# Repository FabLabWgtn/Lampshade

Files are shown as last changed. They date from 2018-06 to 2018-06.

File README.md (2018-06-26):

# README

Wendy Neale, Designer and Director of [Fab Lab Wgtn](https://www.fablabwgtn.co.nz/), in New Zealand was the Mentor-in-Residence at [Fab Lab UAE](http://fablabuae.ae/) from January to July 2018, during Fab Academy. In the fifth week of Fab Academy, the Lab hosted the first Mini MakerFaire in the UAE. Fab Lab UAE asked her to design a paper lampshade for some casual workshops that would run during the four-day event. Here is what she did:

With everything else going on in the Lab, I found myself with only a couple of days to prepare, so I spent some time cutting and folding paper and trying out some ideas. I needed to work more quickly, so I decided to build on some existing work rather than developing it from the beginning. Looking at the Crease Patterns created by RJ Lang, I decided to adapt the CamphorPot8, opus 679. Referencing this pattern added to the story as I was able to talk about the work he did on the [Deployable Solar Array](https://compliantmechanisms.byu.edu/node/892), where he built on someone else's work, showing the benefit of not starting from zero. It's also a great example of the broader uses of paper-folding!

RJ Lang's website is full of great patterns that he has developed, and if you look around it, you will find that he has very clear copyright statements. He is open to uses of his patterns for educational purposes as long as you have his written permission and always give credit to him for his crease patterns.

I drew up a file in Illustrator and tested it and modified it a number of times. One day, I might make it in something else, but I was in a hurry and wasn't too concerned about other people being able to edit it.”

After the four-day event, she collaborated with Etienne Moreau, Technical Demonstrator at [Fab Lab Wgtn](https://www.fablabwgtn.co.nz/) in New Zealand from February to July 2018, to work on the lamp prototype she started and create a 2-hour workshop to help people learn to make their own custom lampshades! Along with the file and material settings, you’ll find the workshop run-sheet including steps to learn how to do it on your own!

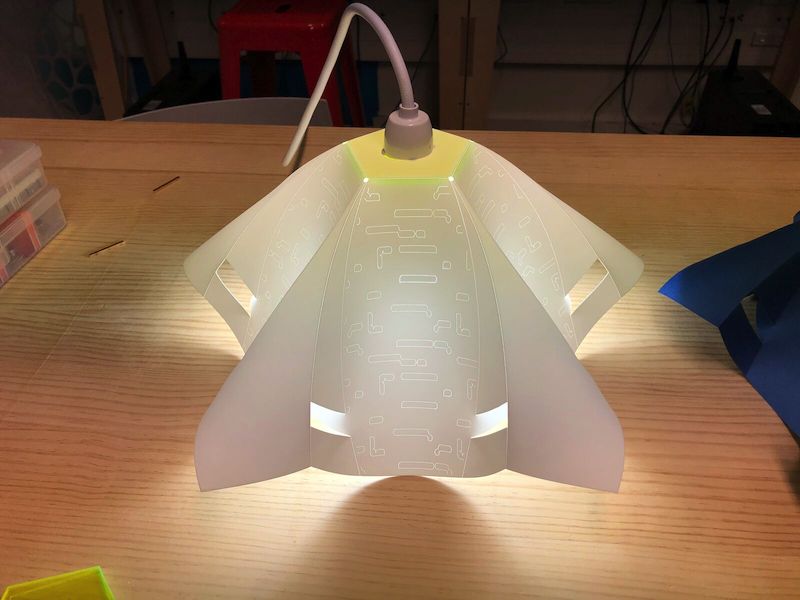
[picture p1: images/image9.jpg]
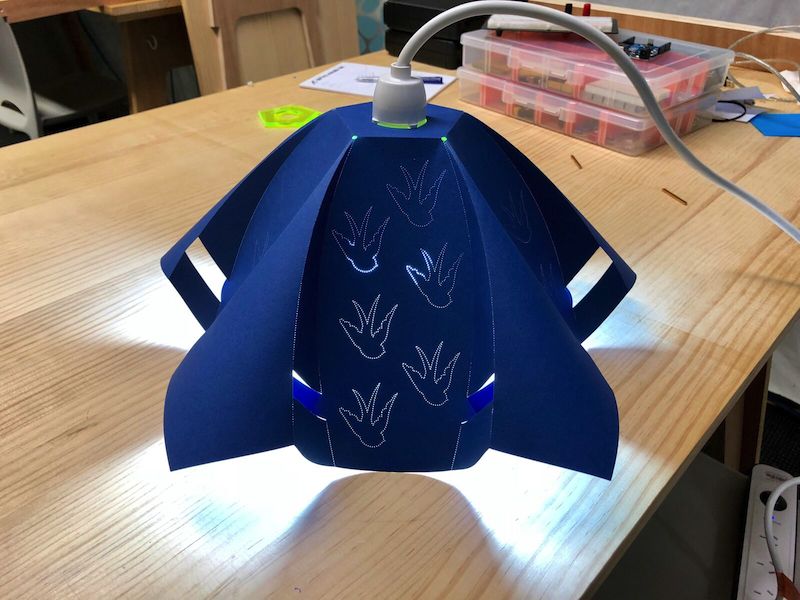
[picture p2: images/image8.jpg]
 

> *Fab Lab Wgtn Lampshade (white model) and a custom model made by a community member (blue model)*

---

## **Files in this repo**

  - a **Lampshade template** in **.ai** and **.dxf** format to make your custom design

  - the [Materials list, settings & machine specs](Materials-list-settings-machine-specs.md)

  - a [Workshop runsheet](DIY-instructions-workshop-runsheet.md) to run your own Lampshade workshop

  - the [Instructions to hand out to participants](Instructions_participants_workshop.pdf) attending the workshop

  - **Fab Lab Wgtn’s Lampshade** ready-to-cut sample in **.ai** and **.dxf** format

  - **others custom designs** we made at Fab Lab Wgtn in **.ai** and **.dxf** format

----

## **Machine & software used**

To create our lamps, we only used:

- a **laser cutter** (machine/process available in many Fab Labs - ours is a ILS12.150D Universal, powered with a 105W laser unit, with a bed-size of 1219.2x609.7mmm)

- **Adobe Illustrator vector drawing software** (a good free & open source alternative is Inkscape!)

---

## **Materials recommended**

So far, we made great lampshades out of

- **0.6mm polypropylene** (the white model) or **0.35mm colored craft paper** (the dark blue model)

- and **3mm acrylic** (for the light socket fitting)

----------

## **Layout of the Lampshade template**

The page size is equal to our laser cutter bed size. There are 6 layers in the document and 3 art-boards (the Universal Laser print driver can deal with more than one art-board). There are also graphic styles already pre-set to prepare the file for laser cutting (pure red 0.1 pt stroke to cut, pure green 0.1 pt stroke to make creasing lines)

  - **The 3 art-boards are**:

    - art-board 1 - to cut the final lamp

    - art-board 2 (below) - to work on your very own lamp design
    - art-board 3 (right) - to cut the acrylic fitting

--

  - **The 6 layers are**:

    - the notes & black guides (on art-board 1)

    - the lamp red cutouts (on art-board 1)

    - the lamp green creasing lines (on art-board 1)
    - a draft layer dedicated to prep your design (on art-board 1)

    - the acrylic fitting (on art-board 3 - on the right side)

    - the logos & credits for the acrylic fitting (on art-board 3 - on the right side)

--

  - **Black lines are guides**:

    - The thin grey dotted lines are symetry guides

    - The thick black lines are guides to align your design with the first petal of the Lampshade

--

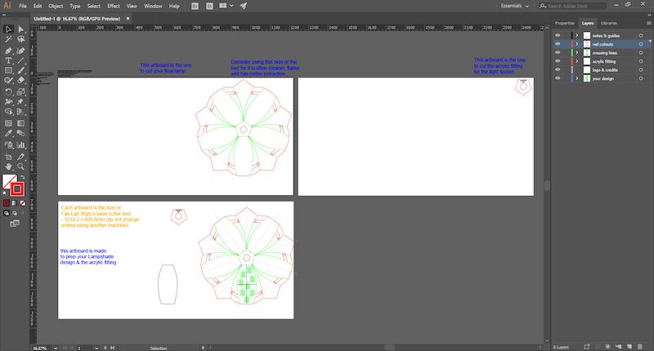
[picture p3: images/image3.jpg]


>  *what the Lampshade vector template looks like in Illustrator*

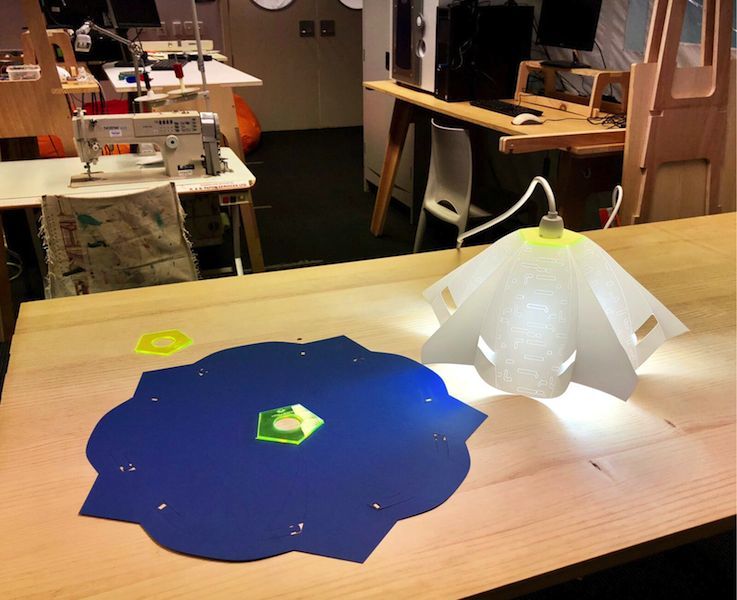
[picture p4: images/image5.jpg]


> *a ready-to-fold Lampshade & a finished model*

----------
## **Workshop layout - create a “2-hour make your own lampshade” workshop**

- **License** - Creative Commons Attribution-NonCommercial-ShareAlike 4.0 International License

  Creative Commons Attribution-NonCommercial-ShareAlike 4.0 International License.

- **original design** - Wendy Neale, based on an existing pattern by R. J. Lang

- **workshop creators** - Wendy Neale & Etienne Moreau (Fab Lab Wgtn)

- **creation date** - May 2018

- **workshop type** - hands-on workshop, 2 hours

- **advised number of participants** - 6

- **machine needed** - laser cutter with at least a 500x500mm bed

- **software needed** - vector drawing software like Inkscape or Illustrator

- **suggested materials** - for each lamp, a 500x500mm piece of 0.6mm white polypropylene or 0.35mm colored paper + a 85x80mm piece of 3mm acrylic

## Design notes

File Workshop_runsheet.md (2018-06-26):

# Workshop runsheet - make your own Lampshade in 2 hours



### **WORKSHOP LAYOUT**

  - **original design** - Wendy Neale, based on an existing pattern by R. J. Lang
  - **workshop creators** - Wendy Neale & Etienne Moreau (Fab Lab Wgtn)
  - **date** - May 2018
  - **license** - Creative Commons Attribution-NonCommercial-ShareAlike 4.0 International License
  - **workshop type** - hands-on workshop, 2 hours
  - **advised number of participants** - 6
  - **machine needed** - laser cutter with at least a 500 x 500mm bed
  - **software needed** - vector drawing software like Inkscape or Illustrator
  - **material to be cut** - for each lamp, a 500 x 500mm piece of 0.6mm white polypropylene or 0.35mm colored paper + a 85 x 80mm piece of 3mm acrylic
----------
**ABOUT THE LAMPSHADE**

  Inspired from Robert J. Lang’s [CamphorPot8, opus 679](http://www.langorigami.com/crease-pattern/camphorpot8-opus-679) origami pattern, this Lampshade was created in Dubaï by Wendy Neale, while working at [Fab Lab UAE](http://fablabuae.ae/). It was then adapted in Wellington by Etienne Moreau ([Fab Lab Wgtn](https://www.fablabwgtn.co.nz/)) to help anyone custom their own Lampshades & run workshops!

  The lamp’s story is a great illustration of what we can make & achieve in an open design world with shared digital fabrication spaces all around the world available to anyone!

----------
**TODAY'S PLAN**

  In 2 hours, we’ll make a plan to make our lamps, find cool illustrations on the web, prepare your unique design with Adobe Illustrator software, cut your lamp with the laser cutter together, fold it into its final shape & wire it. By then, your creation will be ready to be put anywhere back home or at your office!

  - 0️⃣  welcome everyone & workshop start - **5-10 min**
  - 1️⃣  making & lighting for well-being - **5 min**
  - 2️⃣  find & download free illustrations - **10** **min**
  - 3️⃣  create a custom lampshade - **40 min**
  - 4️⃣  engrave the design - **5-8 min** cut time max per person
  - 5️⃣  crease the lamp - **15 min**
  - 6️⃣  wire the lamp & light it up - **10 min**

---

###  **WHAT WE’RE GOING TO USE TODAY**

- **Adobe Illustrator** (or alternatively any vector drawing software like Inkscape)

Vector drawing softwares are a great tools to draw stuffs in 2D, from illustrations to designing lampshade, paper boxes or other cools projects! It’s also a great tool to create something we want to laser cut!

And the good thing is, it’s pretty to learn and get started. We’ll use it to adapt an illustration created by someone else and use it as a base for your lampshade design.

- **A laser cutter**

The laser cutter is the single most used machine in Fab Labs over the world. A laser beam is created and focused to a single point to help us cut/engrave wood, plastic, paper, fabrics and other fun materials & make the thing we designed for us.

Pairing vector drawing & laser cutting is a powerful thing, and one of the best ways to start experiencing digital fabrication!

----------
### **BEFORE MAKING A LAMPSHADE ON YOUR OWN ⚠️**

  - **We recommend buying everything prior to starting these instructions** (for example, you need to know the width of your light socket to set the right dimensions for the acrylic fitting)

  - The workshop & these instructions aren't **meant to be a full introduction to Illustrator & laser cutting**! If you don’t know how to use them, [find a local Fab Lab](https://www.fablabs.io/labs) to learn & practice on simple projects first :)

  - if you don’t have one already, **download a vector drawing software like Adobe Illustrator (not free) or Inkscape (free) and learn the basics through tutorials!**

----

### **BEFORE RUNNING THE WORKSHOP YOURSELF ⚠️**

  - get all the materials you need
  - buy matching lights bulbs, sockets & power leads
  - test out the settings for the chosen material on your own machine
  - make a test lamp with your own design to test the whole workflow

  - pre-cut all lamps but one to save time - cut the last one during the workshop to show participants
  - if you pre-cut the lamps, don't forget to use the workshop Illustrator template and to keep the "outside paper pattern" to be able to engrave the design on the exact same spot

  - adapt the acrylic fitting dimensions to the light sockets you bought
  - pre-cut all acrylic fittings but one to save time - cut the last one during the workshop to show
  - if you pre-cut the acrylic fittings, don't forget to use the workshop Illustrator template and to keep the "outside acrylic pattern" to be able to engrave the participants' names on the exact same spot

  - turn on the machine, focus on the material & choose the right settings
  - print these instructions for everyone

----------

## 0️⃣  **WELCOME EVERYONE & START WORKSHOP - 5-10 min**

  - welcome everyone to the space you run the workshop in
  - explain briefly the goals of the workshop & what can everyone expect
  - introduce yourself, talk about your experience and how this workshop is exciting to you
  - ask everyone to introduce themselves: where they’re from, their background, experience with digital fabrication (both machine & software side) and what they’re trying to achieve participating in this workshop
  - thank everyone & explain the outline of the workshop

----------

## 1️⃣  **MAKING & LIGHTNING FOR WELL-BEING - 5 min**

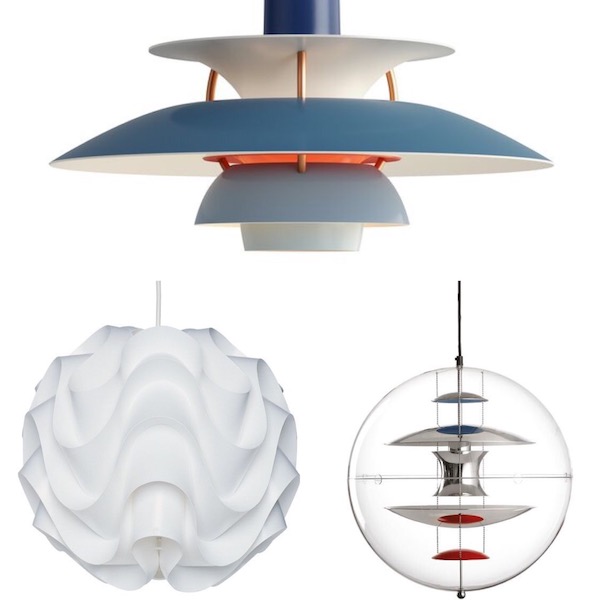
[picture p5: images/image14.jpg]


*read for more context about lighting at home & for well-being, these pictures are taken from* [*The Little Book of Hygge: Danish Secrets to Happy Living*](https://www.theguardian.com/books/2016/sep/29/book-of-hygge-louisa-thomsen-brits-review) *written by Meik Wiking*

----------
- **why make a lamp ourselves instead of buying one?**
  - it’s always an invaluable learning opportunity to make something yourself 🙂
  - using a laser cutter, you’ll get spend a great moment in a local community space
  - you’ll learn to create something, not existing on the market and fitting your needs & personality
  - making locally rather than buying something made abroad & shipped is better for the planet
  - you’ll start taking control back over the objects & physical world around you (invent, repair, adapt, make things again)

- **key take-aways about lighting for well-being**
  - the lower the temperature of the light, the best for our eyes & bodies
  - between 3,000K (incandescent lamp) & 1,800K (sunset, candle flame, wood fire) is ideal
  - as much, try to eliminate visual glare, obscure the light source to only emit reflected light
  - instead of having one bright spot in the room, have several warm light spots
  - the position of lighting is the most important thing in your home, more than room layout
  - making & Fab Labs are an opportunity to create lightnings for you & your well-being

----------

## 2️⃣  **FIND & DOWNLOAD FREE ILLUSTRATIONS - 10 min**

Because designing an illustration from scratch is a whole other business, people created amazing websites where you & I can download illustrations made by real designers for free. Pretty cool uh? We’ll download one you like to start!

-  go to The Noun Project

- choose a simple illustration of something waves or animals (see the example below to know how to choose)

💡 *Our goal here is to have as few lines as possible. The more lines, the longer the cut. Choose your design wisely!*

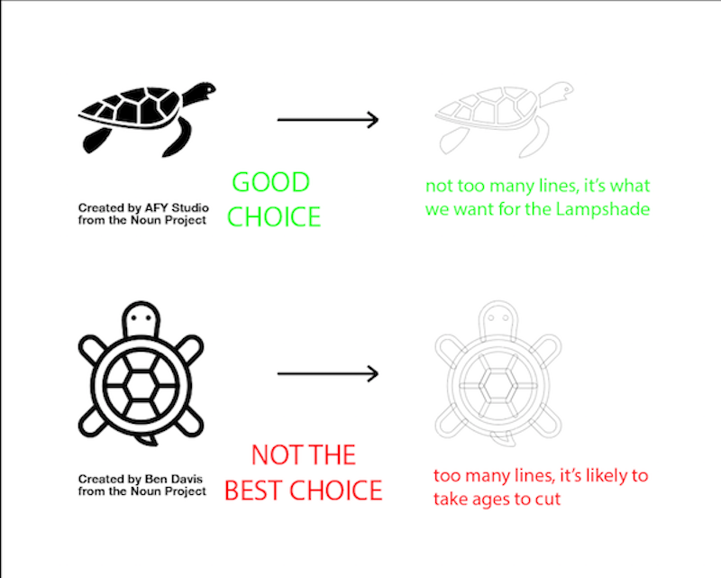
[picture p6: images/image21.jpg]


⚠️  *Before hitting “Download”, look at the license protecting the design (hover the small icons next to the download button with your mouse) & wonder if the use you’ll make of it matches the license*

- choose the SVG option

- create an account or log in

- choose the Creative Commons option

- open it with Adobe Illustrator

⚠️  *Don’t delete the credits, they’re important - note them / take picture for later reference. Deleting them and using the design in one of your project just like that = plagiarism!*

**→ good job choosing your illustration, let’s open it in Illustrator to adapt it to create your own Lampshade**

----------

## 3️⃣  **CREATE A CUSTOM LAMPSHADE - 40 min**

💡 *We use Adobe Illustrator at Fab Lab Wgtn - hence, the following instructions are named after the Illustrator ones, but you’ll easily find how to do it in another software on Google!*

**STEP 3.1 - ADAPT THE ILLUSTRATION TO CREATE YOUR DESIGN**

The person who created the illustration we just downloaded has surely done a bunch of stuffs to it: grouping elements, organizing the elements in layers & masks, using clipping masks to create the shapes, and more Illustrator complicated stuffs!

So the first step will be to get rid of all of this to only a simple illustration ready to be modified!

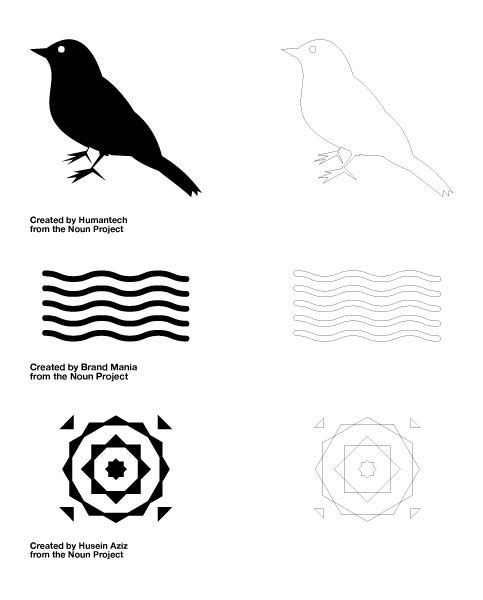
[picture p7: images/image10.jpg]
 *examples of illustrations downloaded from The Noun Project and “cleaned” to create our Lampshade design*

Now in Illustrator, make sure you:

 - **get rid of all the groups**
= select everything with “ctrl + A”, then do “ctrl + shift + G” several times to ungroup everything

 - **get rid of all the compound paths**
= select everything with “ctrl + A”, then go to the top menu to “object” > “compound path” > “release”

 - **get rid of all the clipping mask**
= select everything with “ctrl + A”, right-click on one of the design lines, then select “cancel clipping mask” if there’s any

 - **get rid of all the double/superposed lines**
 = erasing one line to see if there’s any doubloons hiding underneath it, then do “ctrl + Z” to cancel the deletion

 - **save your work with “ctrl + s”**

**→ good job preparing your illustration, let’s now create our “illustration pattern” over the whole Lampshade**

----------

**STEP 3.2 - OPEN THE LAMPSHADE TEMPLATE WE PREPARED**

To make this 2-hour workshop available to anyone & focus on the essential, we create a ready-to-use Lampshade template in Illustrator! We organised it and prepared everything you’ll need to make your own Lampshade. Before opening it, here is what it looks like and what’s inside!

 *what the Lampshade template looks like in Illustrator*

💡 *Each art-board size is the same as Fab Lab Wgtn laser bed size (1219x609mm)*

- open the Lampshade template

- **The 3 art-boards are**:

  -  art-board 1 - to cut the final lamp
  - art-board 2 (below) - to work on your very own lamp design
  - art-board 3 (right) - to cut the acrylic fitting

- **The 6 layers are**:

  - the notes & black guides (on art-board 1)
  - the lamp red cutouts (on art-board 1)
  - the lamp green creasing lines (on art-board 1)
  - a draft layer dedicated to prep your design
  - the acrylic fitting (on art-board 3 - on the right side)
  - the logos & credits for the acrylic fitting (on art-board 3 - on the right side)

- The **thin grey dotted lines** are symmetry guides

- The **thick black lines** are guides to align your design with the first petal of the Lampshade

----------

**STEP 3.3 - FROM ONE ILLUSTRATION TO A PETAL-SIZED PATTERN**

Now that your illustration is ready, we can create a pattern of illustrations on the first petal of the Lampshade (out of 5): we’ll adapt the scale, the orientation, the alignment and the number of illustrations we want before replicating this petal over the whole Lampshade!

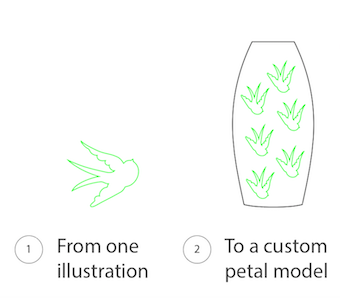
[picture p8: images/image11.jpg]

*adapting & replicating our illustration to create a petal-sized design*

💡 *again, the smaller the result & the more illustrations, the longer the cut! We’d recommend making your first lamp with a design not too small & not too complex!*

Now in Illustrator, make sure you:

- in your illustration file, select only the design and copy it with “ctrl + C”
- now in the Lampshade template, zoom on the black petals
- paste your illustration with “ctrl + V”

- **change your illustration style** - go to “window” in the top menu > click on “graphic styles” > select the green outline one - this graphic style will set the fill color to clear, the outline color to pure green and the stroke weight to 0.1 pt
- group all your illustration lines together (use ctrl + G) - now, wherever you click, it will select everything by default
- move your illustration over one of the locked black petals

- **change the scale of your illustration** (in the top menu, go “window” > “properties” > tick the “keep the ratio” box and update the width or height to a small-enough size)
- **change the orientation of your illustration** (hit “R” key, click & drag to turn) - the top of petals are the one adjacent to the pentagon in the middle of the Lampshade
- **create an “illustration wallpaper" on the petal by multiplying your illustration** (copy with “ctrl + C”, paste with “ctrl + V” & place by selecting and moving it)
- **align or distribute all your illustrations in a nice way** (in the top menu, go “window” > “align” and check out the different options)

- select everything inside the petal and group it together with “ctrl + G”

- **save your work with “ctrl + s”**

**→ good job, your petal-sized design is finished**

----------

**STEP 3.4 - FROM A PETAL-SIZED PATTERN TO A WHOLE LAMPSHADE**

Now that out petal-sized pattern is ready, we will just copy it, place it over the next petal and repeat these steps to finish our Lampshade design. And Illustrator has handy functions that will help us do it in just a few steps!

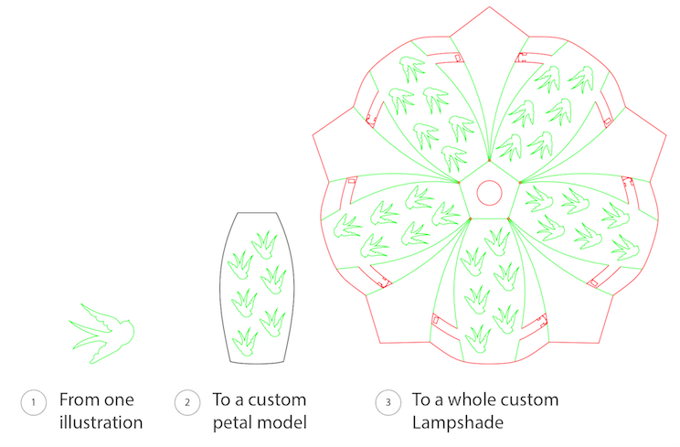
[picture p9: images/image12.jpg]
 *all 3 steps from one illustration to a whole custom Lampshade*

Now in Illustrator, make sure you:

- hide the layer with the black guides - go to the “layer menu” and click on the small eye next to the “notes & guides” layer - all the black guides and notes should disappear

- select your illustrations group from the petal model
holding the shift key, select the red circle
releasing the shift key, click on the red circle again (should appear thicker)
- go to the “align menu”, select the second option - horizontal align center
- your illustrations group should now be over the lamp’s first petal without touching the edges

- select your illustrations group again
- hit the “R” key to enter the rotation mode
- holding the “alt” key, click on the red circle’s center - a dark rotation menu should open
- you want to set the angle to 72° and make sure you click on “copy” (not on “OK”)
- hit “ctrl + D” to repeat the last action and place your illustrations group around the Lampshade

- select the whole Lampshade and move it to the top-left artboard

- save your work with “ctrl + s”

**→ congratulations, your custom lamp design is finished**

----------
**STEP 3.5 - CUSTOMISE YOUR ACRYLIC FITTING**

Now that our lamp’s design is finished, we just have to custom the acrylic fitting! This part is not to be forgotten, it will hold the light socket & bulb firmly in place

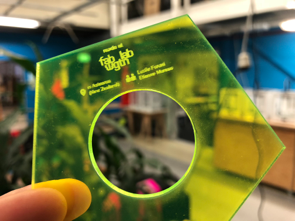
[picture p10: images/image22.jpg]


- go on the top-right artboard, double-click on the text box

- write your name, the date and the place where you created the design!

- save your work with “ctrl + s”

**→ congratulations, your lamp’s acrylic fitting is now finished too**

----------

## **4️⃣ CUT THE LAMP & THE ACRYLIC FITTING**

For this workshop to be short enough, we pre-cut some off the lamps & acrylic fittings! But we’ll cut a whole one from the start for you to understand how it works and enjoy the process. Then we’ll engrave everybody’s lamp design and acrylic fittings!

Here are a few troubleshooting tips before cutting the lamp & the acrylic fitting:

- we need to focus the laser cutter perfectly for each material
- we need to use only perfectly flat materials as much as possible
- we’ll cut all the green lines (creasing lines & your design) first, then the red lines to avoid material warping and its consequences
- to avoid having burnt traces under your material, we will spread sheets of classic print paper under your material before adding the polypropylene on top
and last, we’ll time your file to know exactly how long it will take (we recommend 10 min max for one lamp)

💡 *It is very important to actively supervise the machine during the cut! This is not the time to hang in the other room and chat with everyone. If you’re not confident enough, better ask someone to check your file and remind you all the health & safety practices* ;)

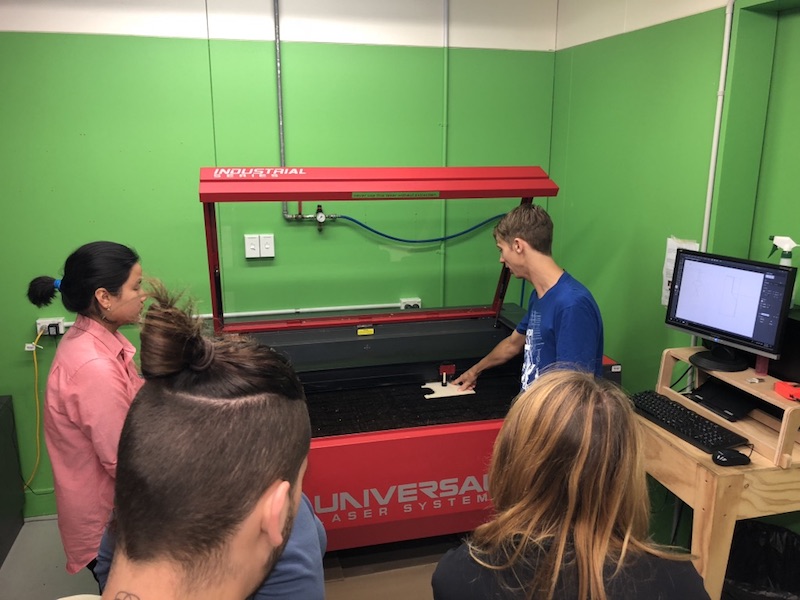
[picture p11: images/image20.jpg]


- Once the cut is done, before touching/removing your material, we will check if it’s cut all the way through:

- if not, launch a new job only with the red lines (deleting or hiding the green ones)
if yes, we can safely remove your material

**→ your custom lamp & acrylic fitting are now cut and ready to be creased**

----------

## 5️⃣  **CREASE THE LAMP - 15 min**

 *a ready-to-fold Lampshade & a finished model*

Now that our lamp is cut, we want to crease it & gently encourage it to be the shape it secretly wants to be! Don’t try to fold it straight away for it would ruin the result!

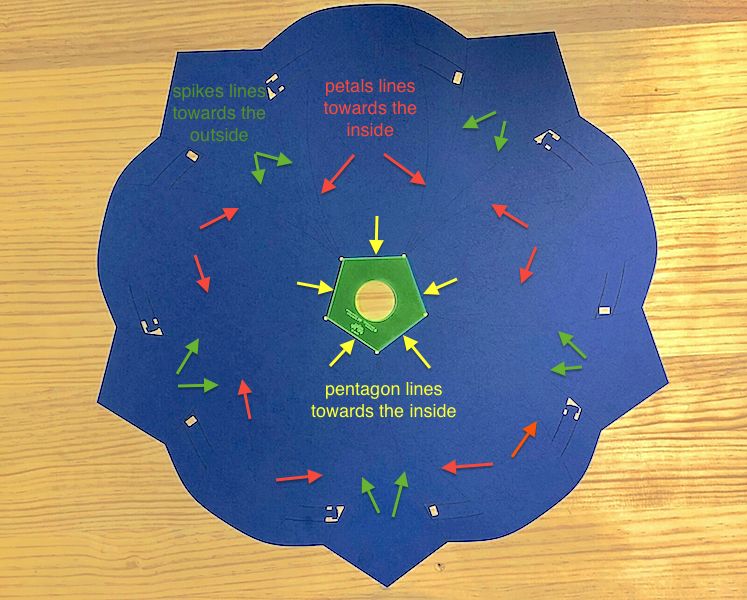
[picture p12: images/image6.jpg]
 *the creasing instructions*

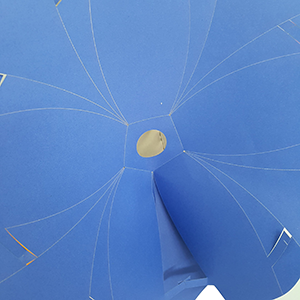
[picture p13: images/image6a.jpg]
 *the creasing instructions*
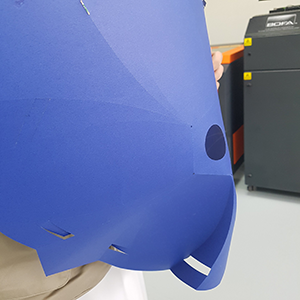
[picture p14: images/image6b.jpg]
 *the creasing instructions*

The top of your lamp will be the outside, while the bottom (with the slight burnt traces from the laser cutter) will be the inside.

- step 1 - crease the pentagon lines from the outside towards the inside
- step 2 - crease the petals edges lines from the outside towards the inside towards the inside
- step 3 - crease the “spikes” edges lines from the inside towards the inside towards the outside
- step 4 - gently squeeze each male latch inside each adjacent female latch
- step 5 - once you’ve attached all the latches together, the lamp should fold itself into its final shape

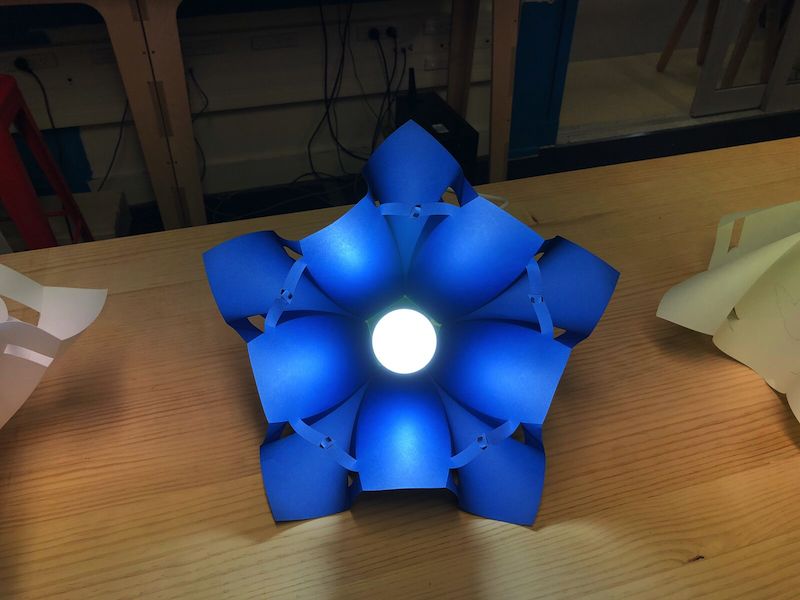
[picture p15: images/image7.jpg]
 *what the Lampshade inside looks like once creased and all latches attached*

Remember to take time check the creasing lines around the whole lamp & creasing just a little more where needed to get a nice, consistent symmetrical result!

  →  **congratulations, your custom lampshade folded in its final origami flower shape :)**

----

## 6️⃣  **WIRE THE LAMP & LIGHT IT UP - 5 min**

⛔️ ⚠️  ***Wiring up electrical appliances is a serious matter and the results of an amateur job could be devastating for your you & those around you. The Internet is not enough and bad/insufficient advices are too common. So if you’ve never done it before, I very strongly recommend you to seek help in a local Fab Lab or to someone with the right experience / expertise to walk through it.***

The steps are to:

  - screw the light socket both from the inside and the outside of the acrylic fitting for a nice & strong fit
  - wire up the power lead to the light socket
  - plug the now all wired lampshade
  - enjoy the result!

  →  **congratulations, you made your first custom lampshade :) Don’t forget to share your creations with us on** [Facebook](https://www.facebook.com/FabLabWGTN/) **or** [Instagram](https://www.instagram.com/fablabwgtn/)**!**



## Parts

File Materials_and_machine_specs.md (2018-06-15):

# Materials list, settings and machine specs

## **Machine - laser cutter specs**

To create our lamps, we only used a laser cutter (machine/process available in many Fab Labs)

- Fab Lab Wgtn's laser cutter is a ILS12.150D Universal
- powered with a 105W laser unit
- with a bed-size of 1219.2x609.7mmm

--



> *Fab Lab Wgtn’s laser cutter!*

----------
## **Material tests**

So far, we made great lampshades out of

  - **0.6mm polypropylene** (the white model) or **0.35mm colored craft paper** (the dark blue model)

  - and **3mm acrylic** (for the light socket fitting)

--

We also tested the following materials for the lamp without much success

- **0.45mm craft paper was too thick**, it made the creasing too difficult

- **0.15mm & 0.20mm craft paper was too thin**, the final structure couldn’t hold itself

--



> *Fab Lab Wgtn Lampshade, made of white polypropylene with a yellow fluo acrylic fitting*

----------
## **List of materials for one lamp**

To create one lamp and light it up, we recommend getting

- a 500x500mm piece of **0.6mm polypropylene** or **0.35mm colored craft paper**

- a 85x80mm piece of **3mm acrylic**

- a **light bulb** (between 1,800K and 3,000K)

- a **light socket** not too large (we used one with 33mm diameter & found a matching light bulb)

- a **power lead** (prior to buying, think of where you’ll put it & the length you need)

----------
## **Material settings for the laser cutter**

All vectors, print in order. The **settings on the picture are for the 0.6mm polypropylene**.

**For all materials but the acrylic, you will see that the PPI for colour blue is down to 20 pulses per inch.**

**This makes a dotted line instead of a continuous line**, allowing light to escape as well as making it easier to crease the card in the direction you want it to, and create a sweet result for your customised illustrations on the petals!

--

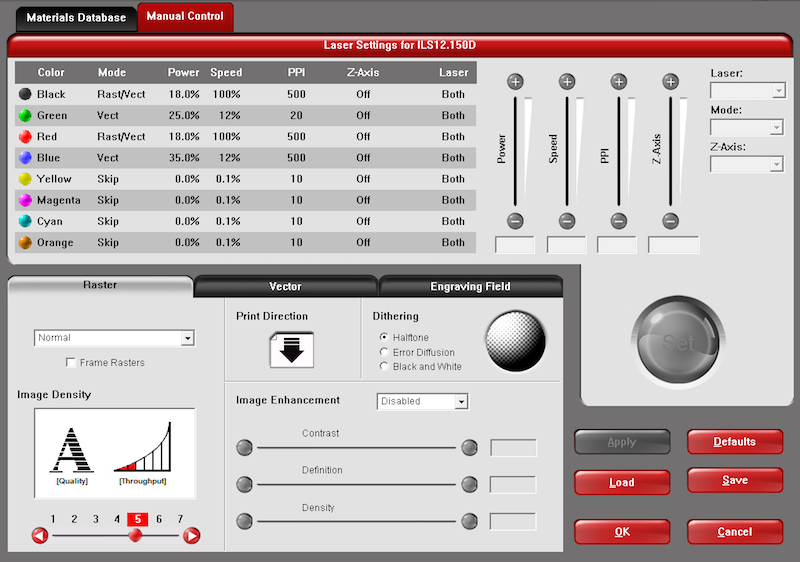
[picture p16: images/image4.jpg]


> *the Universal laser laser cutter material settings for 0.6mm polypropylene (we used red for cutting and green for creasing lines & our design)*

--

> **OPTION #1 FOR LAMP MATERIAL - 0.6mm polypropylene (the white model)**

- **red lines - cut**
  - 50% power
  - 12% speed
  - 500 PPI

- **green lines - creasing + custom design**
  - 25% power
  - 12% speed
  - 20 PPI

--

> **OPTION #1 FOR LIGHT SOCKET FITTING - 3mm acrylic (the yellow fitting for the light socket)**

- **black areas - raster your logo & name**
  - 18% power
  - 100% speed
  - 500 PPI

- **red lines - cut**
  - 100% power
  - 7.5% speed
  - 1000 PPI

--

> **OPTION #2 FOR LAMP MATERIAL - 0.35mm craft paper (the dark blue model)**

- **red lines - cut**
  - 12% power
  - 12% speed
  - 500 PPI

- **green lines - creasing + custom design**
  - 4% power
  - 12% speed
  - 20 PPI

--

> **OPTION #3 FOR LAMP MATERIAL - 0.25mm craft paper**

- **red lines - cut**
  - 8% power
  - 12% speed
  - 300 PPI

- **green lines - creasing + custom design**
  - 4% power
  - 12% speed
  - 20 PPI

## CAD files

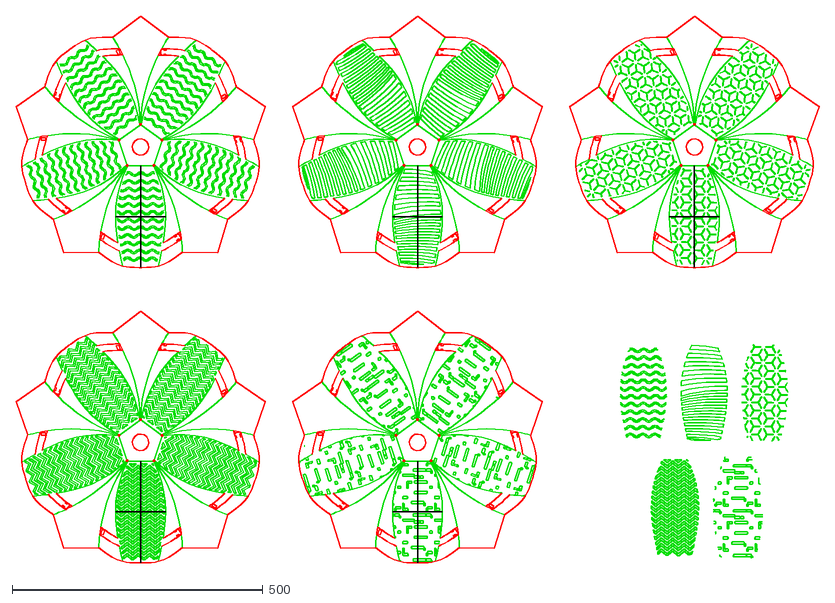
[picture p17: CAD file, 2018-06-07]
ai & dxf files/other_lampshade_designs.dxf
1600.9 x 1090.3

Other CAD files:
ai & dxf files/FabLabWgtn_lampshade_example.dxf
ai & dxf files/Lampshade_template.dxf

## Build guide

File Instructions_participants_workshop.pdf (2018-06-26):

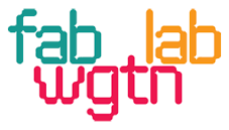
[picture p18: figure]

# Making your own Lampshade !"

- a DIY workshop by Fab Lab Wgtn

ABOUT THE LAMPSHADE

Inspired from Robert J. Lang’s CamphorPot8, opus 679 (http://www.langorigami.com/crease-pattern/camphorpot8-opus-679) origami pattern, this Lampshade was created in Dubaï by Wendy Neale, while working at Fab Lab UAE. (http://fablabuae.ae/)

It was then adapted in Wellington by Etienne Moreau (technical demonstrator at Fab Lab
Wgtn) (https://www.fablabwgtn.co.nz/) to help anyone custom their own
Lampshades!

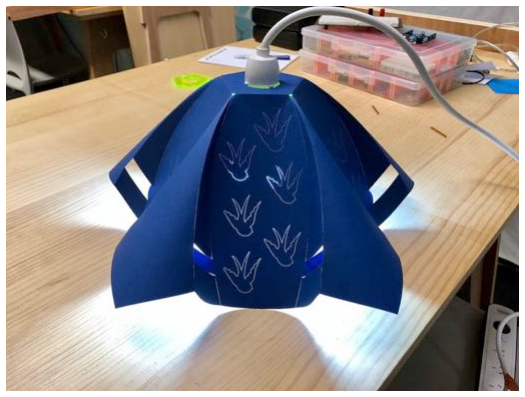
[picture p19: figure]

The lamp’s story is a great illustration of what we can make & achieve in an open design environment with shared digital fabrication spaces around the world available to anyone!

THE LAMPSHADE WORKSHOP

Fab Lab Wgtn team prepared something special to make our homes a little cosier! Join us for this hands-on session, you’ll learn to make a custom origami lamp in 2 hours & have a great time together in our community workshop!

TODAY’S PLAN

In 2 hours, we’ll make a plan to create our custom lamps, find cool illustrations on the web, prepare your unique design with Adobe Illustrator software, cut your lamp with the laser cutter & fold it into its final shape. By then, your creation will be ready to light your home or your office in a new way! We’ll follow these steps:

# talk about making & lighting for well-being - 5 min

$ find & download free illustrations - 10 min
% create a custom lampshade - 40 min
& engrave your design - 5-8 min cut time max per person ' fold the lamp - 15 min
( light our lamp up - 5 min

WHAT WE’RE GOING TO USE TODAY ) *

- Adobe Illustrator software (or alternatively any vector drawing software like Inkscape)

Illustrator (or Inkscape) is a great tool to draw stuffs in 2D, from illustrations to designing lampshade, paper boxes or other cools projects! It’s also a great tool to create something we want to laser cut!

And the good thing is, it’s pretty to learn and get started. We’ll use it to adapt an illustration created by someone else and use it as a base for your lampshade design +

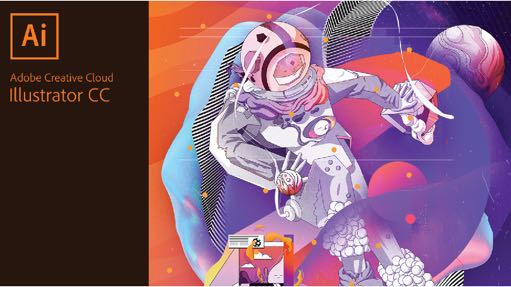
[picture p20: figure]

- A laser cutter

The laser cutter is the single most used machine in Fab Labs over the world. A laser beam is created and focused to a single point to help us cut/engrave wood, plastic, paper, fabrics and other fun materials & make the thing we designed for us.

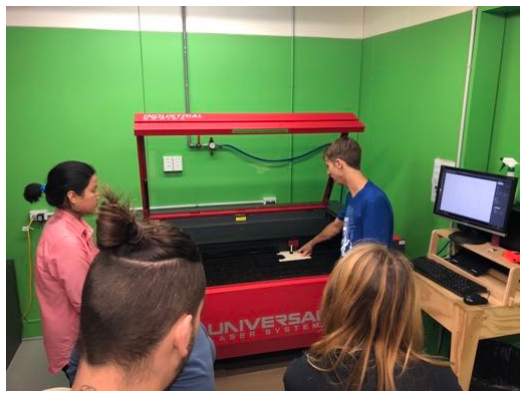
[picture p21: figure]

Pairing Illustrator & laser cutting is a powerful thing, and one of the best way to start experiencing digital fabrication ✨

## # MAKING & LIGHTING FOR WELL-BEING - 5 min

for more context about lighting at home & for well-being, read the chapter about light in The Little Book of Hygge: Danish Secrets to Happy Living (https://www.theguardian.com/books/2016/sep/29/book-of-hygge-louisa-thomsen-brits-review) written by Meik Wiking

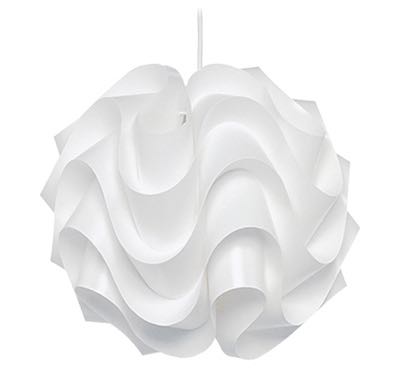
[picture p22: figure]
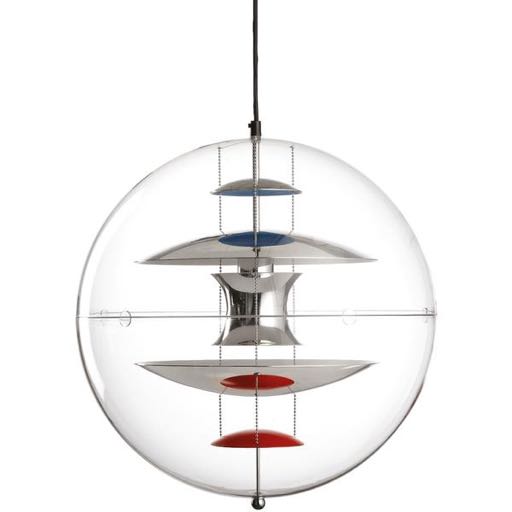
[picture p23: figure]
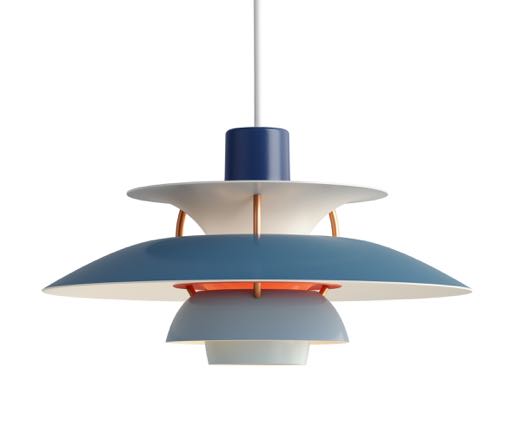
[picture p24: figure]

- why should we make a lamp ourselves instead of buying one?
- it’s always an invaluable learning opportunity to make something yourself
- using a laser cutter, you’ll get spend a great moment in a local community space
- you’ll learn to create something, not existing on the market and fitting your needs & personality
- making locally rather than buying something made abroad & shipped is better for the planet
- you’ll start taking control back over the objects & physical world around you (invent, repair, adapt, make things again)
- the key take-aways for you about lighting for well-being
- the lower the temperature of the light, the best for our eyes & bodies -between 3,000K (incandescent lamp) & 1,800K (sunset, candle flame, wood fire) is ideal
- try to eliminate visual glare as much as possible, obscuring the light source to only emit reflected light
- instead of having one bright spot in the room, prefer having several warm light spots
- the position of lighting is the most important thing in your home, more than room layout

## $ FIND & DOWNLOAD FREE ILLUSTRATIONS - 10 min

Because designing an illustration from scratch is a whole other business, people created amazing websites where you & I can download illustrations made by real designers for free. Pretty cool uh? We’ll download one you like to start!

- go to The Noun Project (https://thenounproject.com/)
- choose a simple illustration of something waves or animals (see the example below to know how to choose)

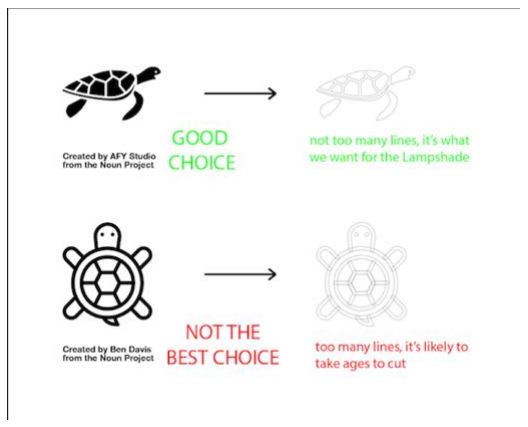
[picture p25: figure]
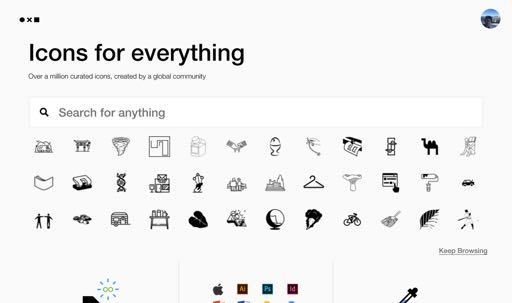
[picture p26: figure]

⚠ Before hitting “Download”, look at the license protecting the design (hover the small icons next to the download button with your mouse) & wonder if the use you’ll make of it matches the license

- choose the SVG option
- create an account or log in
- choose the Creative Commons option
- open it with Adobe Illustrator

⚠ Don’t delete the credits, they’re important - note them / take picture for later reference. Deleting them and using the design in one of your project just like that = plagiarism!

→ good job choosing your illustration, let’s open it in Illustrator to adapt it to create your own Lampshade

## % CREATE A CUSTOM LAMPSHADE DESIGN - 40 min

. We use Adobe Illustrator at Fab Lab Wgtn - hence, the following instructions are named after the Illustrator ones, but you’ll easily find how to do it in another software on Google!

STEP 3.1 - ADAPT THE ILLUSTRATION TO CREATE YOUR DESIGN

The person who created the illustration we just downloaded has surely done a bunch of stuffs to it: grouping elements, organizing the elements in layers & masks, using clipping masks to create the shapes, and more Illustrator complicated stuffs!

So the first step will be to get rid of all of this to only a simple illustration ready to be modified!

. Our goal here is to have as few lines as possible. The
more lines, the longer the cut. Choose your design wisely!

Now in Illustrator, make sure you:

- get rid of all the groups
= select everything with “ctrl + A”, then do “ctrl + shift + G” several times to ungroup everything
- get rid of all the compound paths
= select everything with “ctrl + A”, then go to the top
menu to “object” > “compound path” > “release”
- get rid of all the clipping mask

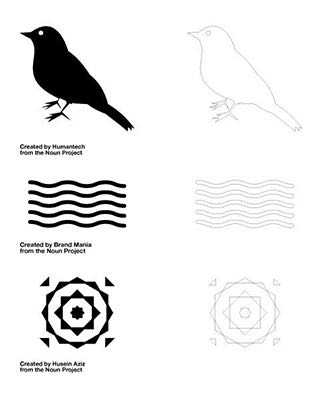
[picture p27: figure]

= select everything with “ctrl + A”, right-click on one of the design lines, then select “cancel clipping mask” if there’s any

- get rid of all the double/superposed lines
= erasing one line to see if there’s any doubloons hiding underneath it, then do “ctrl + Z” to cancel the deletion
- save your work with “ctrl + s”

→ good job preparing your illustration, let’s now create our “illustration pattern” over the whole Lampshade

STEP 3.2 - OPEN THE LAMPSHADE TEMPLATE WE PREPARED

To make this 2-hour workshop available to anyone & focus on the essential, we create a ready-to-use Lampshade template in Illustrator! We organised it and prepared everything you’ll need to make your own Lampshade. Before opening it, here is what it looks like and what’s inside!

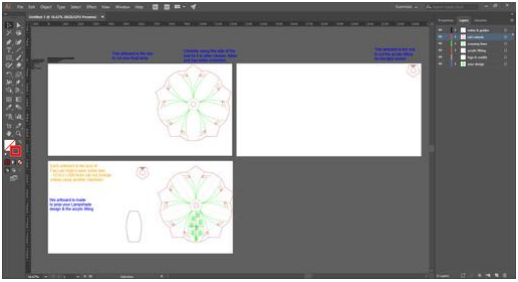
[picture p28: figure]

. Each art-board size is the same as Fab Lab Wgtn laser bed size (1219x609mm)

- open the Lampshade template
- The 3 art-boards are:
- art-board 1 - to cut the final lamp
- art-board 2 (below) - to work on your very own lamp design
- art-board 3 (right) - to cut the acrylic fitting
- The 6 layers are:
- the notes & black guides (on art-board 1)
- the lamp red cutouts (on art-board 1)
- the lamp green creasing lines (on art-board 1)
- a draft layer dedicated to prep your design (on art-board 1)
- the acrylic fitting (on art-board 3 - on the right side)
- the logos & credits for the acrylic fitting (on art-board 3 - on the right side)
- The thin black dotted lines are symmetry guides
- The thick black lines are guides to align your design with the first petal of the Lampshade

STEP 3.3 - FROM ONE ILLUSTRATION TO A PETAL-SIZED PATTERN

Now that your illustration is ready, we can create a pattern of illustrations on the first petal of the Lampshade (out of 5): we’ll adapt the scale, the orientation, the alignment and the number of illustrations we want before replicating this petal over the whole Lampshade!

. again, the smaller the result & the more illustrations, the longer the cut! We’d recommend making your first lamp with a design not too small & not too complex!

Now in Illustrator, make sure you:

- in your illustration file, select only the design and copy it with “ctrl + C”
- now in the Lampshade template, zoom on the black petals
- paste your illustration with “ctrl + V”
- change your illustration style - go to
“window” in the top menu > click on
“graphic styles” > select the green outline

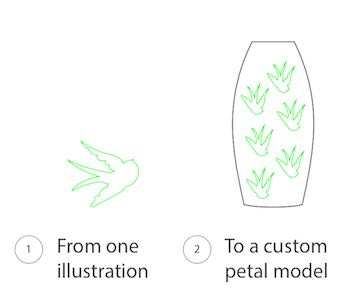
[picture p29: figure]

one - this graphic style will set the fill color to clear, the outline color to pure green and the stroke weight to 0.1 pt
- group all your illustration lines together (use ctrl + G) - now, wherever you click, it will select everything by default
- move your illustration over one of the locked black petals
- change the scale of your illustration (in the top menu, go “window” > “properties” > tick the “keep the ratio” box and update the width or height to a small-enough size)
- change the orientation of your illustration (hit “R” key, click & drag to turn) - the top of petals are the one adjacent to the pentagon in the middle of the Lampshade
- create an “illustration wallpaper" on the petal by multiplying your illustration (copy with “ctrl + C”, paste with “ctrl + V” & place by selecting and moving it)
- align or distribute all your illustrations in a nice way (in the top menu, go “window” > “align” and check out the different options)
- select everything inside the petal and group it together with “ctrl + G”
- save your work with “ctrl + s”

→ good job, your petal-sized design is finished

STEP 3.4 - FROM A PETAL-SIZED PATTERN TO A WHOLE LAMPSHADE

Now that out petal-sized pattern is ready, we will just copy it, place it over the next petal and repeat these steps to finish our Lampshade design. And Illustrator has handy functions that will help us do it in just a few steps!

Now in Illustrator, make sure you:

- hide the layer with the black guides - go to the “layer menu” and click on the small eye next to the “notes & guides” layer -all the black guides and notes should disappear

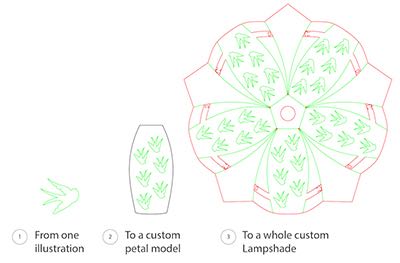
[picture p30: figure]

- select your illustrations group from the petal model
- holding the shift key, select the red circle
- releasing the shift key, click on the red circle again (should appear thicker)
- go to the “align menu”, select the second option - horizontal align center
- your illustrations group should now be over the lamp’s first petal without touching the edges
- select your illustrations group again
- hit the “R” key to enter the rotation mode
- holding the “alt” key, click on the red circle’s center - a dark rotation menu should open
- you want to set the angle to 72° and make sure you click on “copy” (not on “OK”)
- hit “ctrl + D” to repeat the last action and place your illustrations group around the Lampshade
- select the whole Lampshade and move it to the top-left artboard
- save your work with “ctrl + s”

→ congratulations, your custom lamp design is finished

STEP 3.5 - CUSTOMISE YOUR ACRYLIC FITTING

Now that our lamp’s design is finished, we just have to custom the acrylic fitting! This part is not to be forgotten, it will hold the light socket & bulb firmly in place

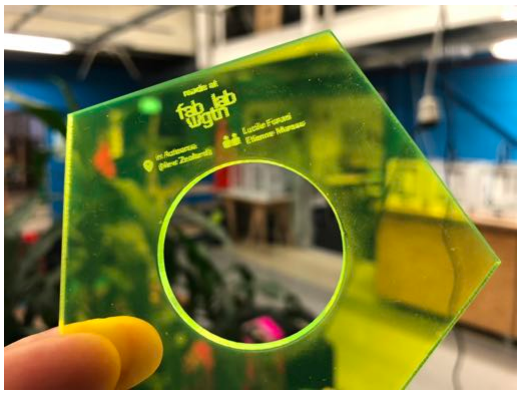
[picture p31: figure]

- go on the top-right artboard, double-click on the text box
- write your name, the date and the place where you created the design!
- save your work with “ctrl + s”

→ congratulations, your lamp’s acrylic fitting is now finished too

## & CUT THE LAMP & THE ACRYLIC FITTING

For this workshop to be short enough, we pre-cut some off the lamps & acrylic fittings! But we’ll cut a whole one from the start for you to understand how it works and enjoy the process. Then we’ll engrave everybody’s lamp design and acrylic fittings!

Here are a few troubleshooting tips before cutting the lamp & the acrylic fitting:

- we need to focus the laser cutter perfectly for each material
- we need to use only perfectly flat materials as much as possible
- we’ll cut all the green lines (creasing lines & your design) first, then the red lines to avoid material warping and its consequences
- to avoid having burnt traces under your material, we will spread sheets of classic print paper under your material before adding the polypropylene on top
- and last, we’ll time your file to know exactly how long it will take (we recommend 10 min max for one lamp)

. It is very important to actively supervise the machine during the cut! This is not the time to hang in the other room and chat with everyone. If you’re not confident enough, better ask someone to check your file and remind you all the health & safety practices ;)

Once the cut is done, before touching/removing your material, we will check if it’s cut all the way through:

- if not, launch a new job only with the red lines (deleting or hiding the green ones)
- if yes, we can safely remove your material

→ your custom lamp & acrylic fitting are now cut and ready to be creased

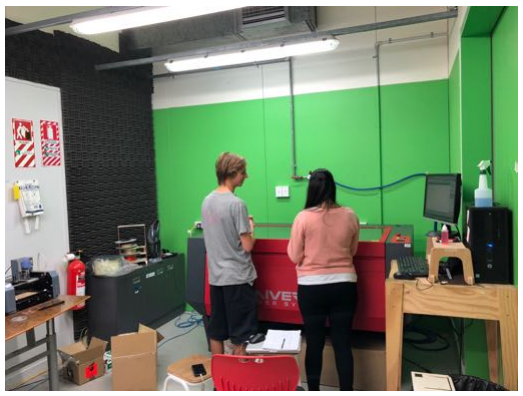
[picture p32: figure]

## ' CREASE THE LAMP

Now that our lamp & acrylic fitting are cut, we want to crease it & gently encourage it to be the shape it secretly wants to be! Don’t try to fold it straight away for it would ruin the result!

The top of your lamp will be the outside, while the bottom (with the slight burnt traces from the laser cutter) will be the inside.

- step 1 - crease the pentagon lines
from the outside towards the inside

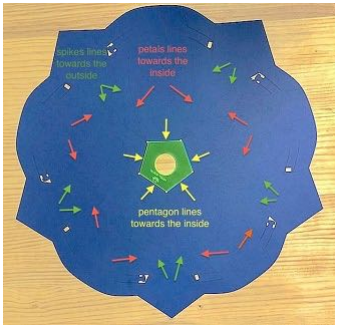
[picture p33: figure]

- step 2 - crease the petals edges lines from the outside towards the inside
- step 3 - crease the “spikes” edges lines from the inside towards the outside
- step 4 - gently squeeze each male latch inside each adjacent female latch
- step 5 - once all latches attached, the lamp should fold into its final shape

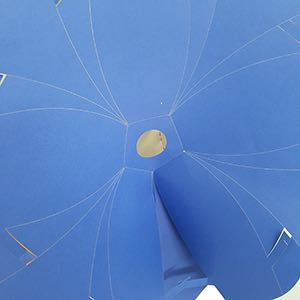
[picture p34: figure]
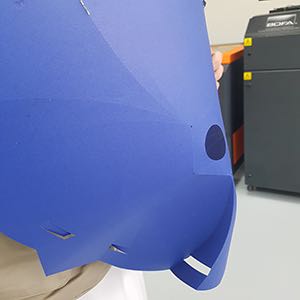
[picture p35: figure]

Remember to take time check the creasing lines around the whole lamp & creasing just a little more where needed to get a nice, consistent symmetrical result!

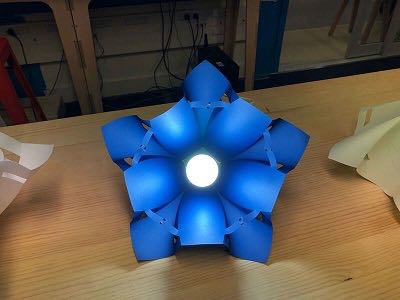
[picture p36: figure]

→ congratulations, your custom lampshade folded
in its final origami flower shape! It’s now ready to
welcome a light socket & bulb, and be lit up to reveal its design!

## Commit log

2018-06-07 created .ai and .dxf templates for workshop & updated ReadMe
    [FabLabWgtn_lampshade_example.dxf, Lampshade_template.dxf, other_lampshade_designs.dxf]
2018-06-07 updated ReadMe, created materials and workshop instructions
    [FabLabWgtn_lampshade_example.dxf]
2018-06-26 Updated notes & files after running the first workshop
    [FabLabWgtn_lampshade_example.dxf, Lampshade_template.dxf]
